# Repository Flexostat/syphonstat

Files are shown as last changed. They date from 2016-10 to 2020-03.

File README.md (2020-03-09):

usage
=====

main.py:

Note that currently this is rough code and as such you have to modify some code constats to change settings.

All configureation is in main.py toward the top.  These variables are clearly labeled.  Currently the only adjustable things are the serial port used and the OD setpoint.

To run, make sure the correct serial port is setup and execute main.py (eg in a terminal, type 'python main.py' without the single quotes).

plot.py:

Used to quickely plot data generated by main.py.  Assuming numpy/scipy are installed, just run 'python plot.py'.

<br />This work is licensed under a <a rel="license" href="http://creativecommons.org/licenses/by/4.0/">Creative Commons Attribution 4.0 International License</a>.

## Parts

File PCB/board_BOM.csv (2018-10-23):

Reference | MPN | qty | note
JP2 |  |  | 3p 0.1in header vertical
C1 |  |  | .1uF x7r or better 16v or higher
C2 |  |  | 0.01uF x7r or better 16v or higher
C3 |  |  | .1uF x7r or better 16v or higher
C4 |  |  | 4.7uF x7r or better 16v or higher
C5 |  |  | 4.7uF x7r or better 16v or higher
C6 |  |  | .1uF x7r or better 16v or higher
U2 | FT232RL
L1 | MI0805K400R-10 or similar
PV1 | 2p 0.1in header vertical
PV2 | 2p 0.1in header vertical
R1 | 180ohm 0805
R3 R5 |  | 2 | 1kohm 0805
X1 | 54602-908LF
CON1 | PJ-002BH-SMT
Q3, Q4 | CJ2302 |  | AO3418
U3 | 74HCT2G04
P1 | ST-USB-009A |  | or UJ2-BH-1-TH
U1 | R-78E05-0.5
D1 | LED, green, 0805

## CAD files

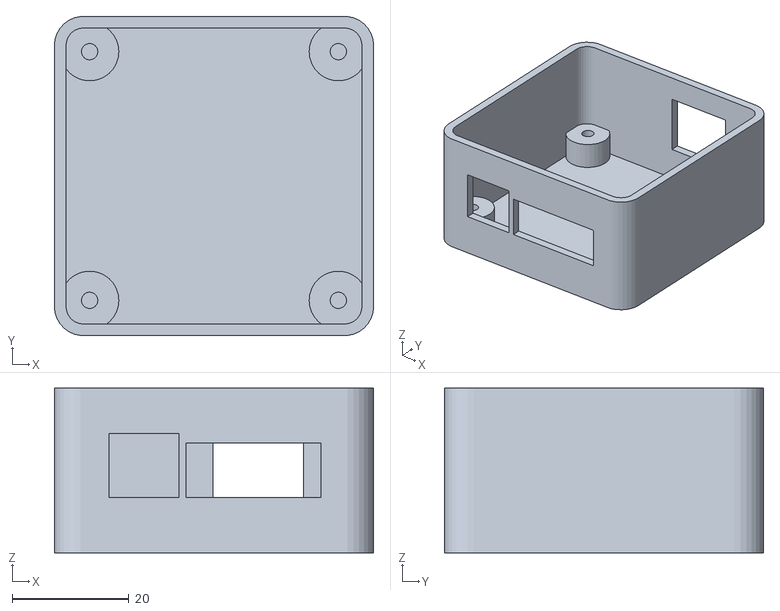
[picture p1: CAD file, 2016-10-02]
3d_printed_parts/Mainboard_base.stl
54.7 x 54.6 x 28.2

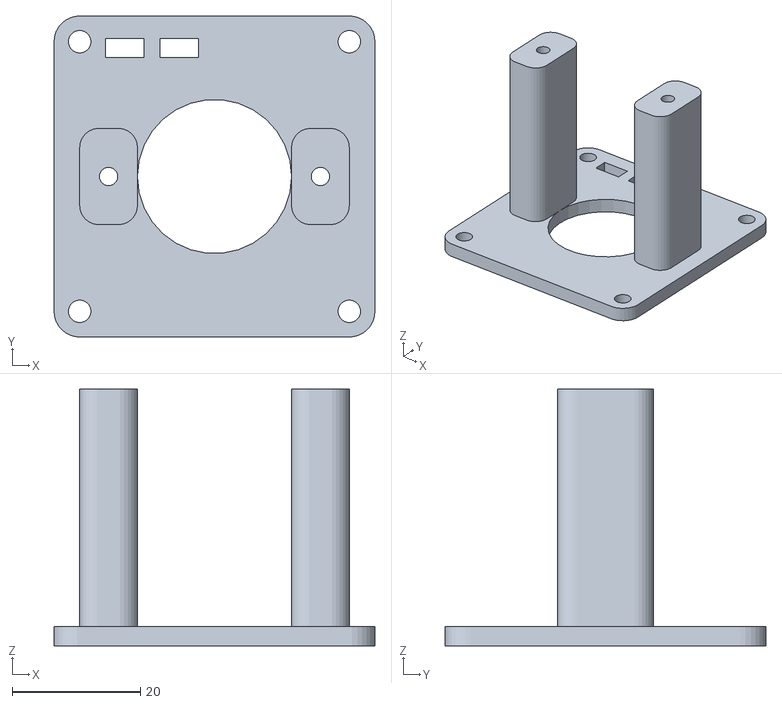
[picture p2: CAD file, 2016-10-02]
3d_printed_parts/PV_holder.stl
50.0 x 50.0 x 40.0

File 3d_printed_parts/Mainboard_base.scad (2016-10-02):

PCB_size = 50;
PCB_thick = 1.5;
extraxy=0.7;
PCB_height = 8;
oah = 30-1.75;
wall = 2;

hole_dim = (PCB_size-2*4)/2+0.3; //shouldn't need the 0.3 but it seems to. 

difference(){
    translate([-PCB_size/2-wall-extraxy/2,-PCB_size/2-wall-extraxy/2,0])
        v_rounded_cube([PCB_size+2*wall+extraxy,PCB_size+2*wall+extraxy,oah] ,5);
    
    translate([-PCB_size/2-wall-extraxy/2,-PCB_size/2-wall-extraxy/2,0])
    translate([wall,wall,wall])
        v_rounded_cube([PCB_size+extraxy,PCB_size+extraxy,2*oah],3 );
    
    //USB cutout
    translate([-PCB_size/2+7,-6-PCB_size/2,PCB_height+PCB_thick])
    cube([12,12,11]);
    //molex cutout
    translate([-23.1+PCB_size/2-6.7,-6-PCB_size/2,PCB_height+PCB_thick])
    cube([23.1,10.3,9.3]);
    //rj45 cutout
    translate([-15.5+PCB_size/2-9.7,-6+PCB_size/2,PCB_height+PCB_thick])
    cube([15.5,10,13.2]);
}
for (ii = [-hole_dim,hole_dim]){
    for (jj = [-hole_dim,hole_dim]) {
        translate([ii,jj]) mount_hole(PCB_height);
    }
}

module mount_hole(h,$fn=30) {
    difference() {
        cylinder(r=5,h=h);
        cylinder(d=2.8,h=h);
    }
}

module v_rounded_cube(xyz,r,$fn=30) {
  z = xyz[2];
  y = xyz[1];
  x = xyz[0];
  translate([r,r])
  hull() {
    cylinder(h=z,r=r);
    translate([0,y-2*r])
    cylinder(h=z,r=r);
    translate([x-2*r,0])
    cylinder(h=z,r=r);
    translate([x-2*r,y-2*r])
    cylinder(h=z,r=r);
  }
}

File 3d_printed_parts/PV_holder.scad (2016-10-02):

size =50;
tap_hole_632 = 2.85; //2.95=tap hole for 6-32.  2.85 = self taping hole for M3
difference() {
  union() {
    translate([-size/2,-size/2])
    v_rounded_cube([size,size,3],r=4);
    for (ii=[-33/2,33/2]) {
      translate([ii-9/2,-15/2,0]) v_rounded_cube([9,15,40],r=3);
    }
  }

  translate([-size/2,-size/2])
  for (ii = [4,size-4]) {
    for (jj = [4,size-4]) {
      translate([ii,jj,0]) cylinder(h=10,d=3.5 , center=true,$fn=30);
    }
  }
  cylinder(h=10,d=24 , center=true);
  for (ii=[-33/2,33/2]) {
    translate([ii,0,0]) cylinder(h=44,d=tap_hole_632 , center=false,$fn=40);
  }
  translate([-size/2+8,size/2-6.5,-1])
  cube([6,3,10]);
  translate([-size/2+8+6+0.1*25.4,size/2-6.5,-1])
  cube([6,3,10]);
}

module v_rounded_cube(xyz,r,$fn=30) {
  z = xyz[2];
  y = xyz[1];
  x = xyz[0];
  translate([r,r])
  hull() {
    cylinder(h=z,r=r);
    translate([0,y-2*r])
    cylinder(h=z,r=r);
    translate([x-2*r,0])
    cylinder(h=z,r=r);
    translate([x-2*r,y-2*r])
    cylinder(h=z,r=r);
  }
}

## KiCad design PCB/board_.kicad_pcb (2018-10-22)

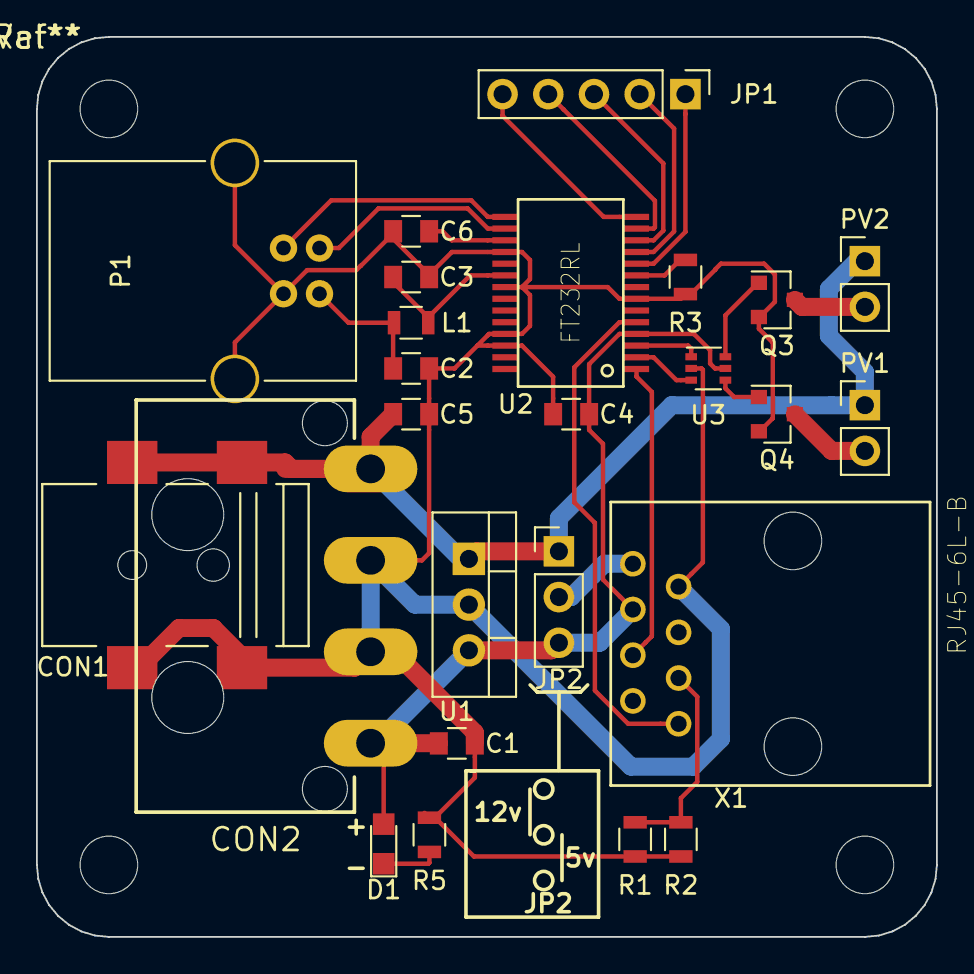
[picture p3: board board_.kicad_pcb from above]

Board: 2 copper layers, 50.0 x 50.0 mm, 26 parts (0 on the bottom side), 25 nets.

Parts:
C1, C3, C6: .1uF; C_0805
C2: 0.01uF; C_0805
C4, C5: 4.7uF; C_0805
CON1: BARREL_JACK; CUI_PJ-002BH-SMT-TR
CON2: 9090-4R; con-thomas-betts-9090-4R
D1: LED; LED_0805
JP1: Pin_Header_Straight_1x05_Pitch2.54mm
JP2: Pin_Header_Straight_1x03_Pitch2.54mm
L1: MI0805K400R-10; R_0805
P1: USB_B
PV1, PV2: Pin_Header_Straight_1x02_Pitch2.54mm
Q3, Q4: Q_NMOS_GSD; SOT-23
R1: 390; R_0805
R2: 330; R_0805
R3, R5: R_0805
Ref**: Val**; DP5050
U1: R-78x05; TO-220_Vertical
U2: FT232RL; SSOP28-LD
U3: 74HCT2G04; SOT-363_SC-70-6
X1: RJ45-6L-B; 54602-908LF

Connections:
+5V: C1.1, C4.1, CON2.1, D1.2, JP2.3, U1.3, U2.4, U3.5, X1.6
+12V: C5.1, CON1.1, CON2.4, JP2.1, PV1.1, PV2.1, U1.1
/RX1E: U2.5, X1.1
/TX1: U2.1, X1.4
GND: C1.2, C2.2, C3.2, C4.2, C5.2, C6.2, CON1.2, CON1.3, CON2.2, CON2.3, P1.4, P1.5, Q3.2, Q4.2, R1.2, R2.2, R3.2, R5.2, U1.2, U2.7, U2.18, U2.21, U2.25, U2.26, U3.2, X1.7
unnamed: JP2.2, X1.8
unnamed: C2.1, L1.1, P1.1
unnamed: C3.1, L1.2, U2.20
unnamed: C6.1, U2.17
unnamed: D1.1, R5.1
unnamed: JP1.1, U2.10
unnamed: JP1.2, U2.11
unnamed: JP1.3, U2.12
unnamed: JP1.4, U2.13
unnamed: JP1.5, U2.14
unnamed: P1.2, U2.16
unnamed: P1.3, U2.15
unnamed: PV1.2, Q4.3
unnamed: PV2.2, Q3.3
unnamed: Q3.1, U3.6
unnamed: Q4.1, U3.4
unnamed: R1.1, R2.1, X1.3
unnamed: R3.1, U2.9
unnamed: U2.2, U3.3
unnamed: U2.3, U3.1

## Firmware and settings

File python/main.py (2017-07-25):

#!/usr/bin/env python
"""Usage: main.py [options]
Options: 
 -?, --help           Prints this message and exits.
 -t, --test           Test mode: displays sensor data as (tx,rx) and exits
     --port=PORT      Sets serial port to PORT.  For windows this should be in 
                      the form COMnnn eg COM1 or COM123.  For nix/MacOS use the
                      path to the serial device eg /dev/cu.usbserial
     --setpoint=f.ff  Sets the OD set point to f.ff OD units.  eg 0.40
     --logfile=of.dat Sets the file used to wirte out log data.

Example: 
  Read sensor data to verify the device is working on COM5
main.py -t --port=COM5

  Run syphoning turbidostat on COM32 at 0.7 OD and write logs to history.dat
main.py --port=COM32 --setpoint=0.7 --logfile=history.dat
"""
from __future__ import print_function

import os
import pickle
import serial
import serial.tools.list_ports
import getopt, sys
from time import sleep, time
from math import log10

#########################################################
#BEGIN: Configuration variables
#vvvvvvvvvvvvvvvvvvvvvvvvvvvvvvvvvvvvvvvvvvvvvvvvvvvvvvvv
LOGFILE = 'log.dat'   #Name of log file
COMPORT = 'COM5'     #name of comport
SETPOINT = 0.4        #OD setpoint
#Gains: bigger kp means a faster controller but more 
# cycle-to-cycle variation in dilution volumes
# hint: keep kp/ki >15
kp = 1000
ki = 25
DILUTE_PERIOD = 60    #how often to dilute in seconds
USE_CONTROLLER_PV = True
#^^^^^^^^^^^^^^^^^^^^^^^^^^^^^^^^^^^^^^^^^^^^^^^^^^^^^^^^
#END: Configuration variables
#########################################################


class Chamber(object):
  def __init__(self,port_name):
    #init instance vars
    self._blankval = None
    self.HW_version = 10 #=v1.0

    #do HW init
    self._init_serial(port_name)

  def close_PV1(self):
    if self.HW_version<11:
      self.spt.setRTS(True)
    else:
      self.spt.setRTS(False) 

  def open_PV1(self):
    if self.HW_version<11:
      self.spt.setRTS(False)
    else:
      self.spt.setRTS(True) 

  def _init_serial(self,p):
    try:
      self.spt = serial.Serial(port = p,baudrate=19200,timeout = 0.5)
      if self.spt.getDSR():
        self.HW_version = 11 #=v1.1
      else:
        self.HW_version = 10
      self.close_PV1()

    except:
      print("Problem opening serial port " + str(p))
      print("available serial ports are: ")
      for cp in serial.tools.list_ports.comports():
        print(cp[0])
      raise ValueError('invalid port')

  def _odbytes2tuple(self,odbytes):
    #correct endianness
    #TODO: replace this with struct.unpack("<ii",data)
    txbytes = odbytes[3::-1]  #first 4bytes
    rxbytes = odbytes[7:3:-1] #next 4bytes
    tx=int(txbytes.encode('hex'),16)
    rx=int(rxbytes.encode('hex'),16)
    return (tx,rx)

  def read_raw(self):
    """
      Read the raw (tx,rx) numbers from chamber.

      This function requests tx,rx data from the chamber and decodes it into
      python int type.

      Returns (tx,rx) tuple.
      Returns None on serial timeout.
    """
    return self.dilute(0)

  def dilute(self,period):
    """
      Dilute chamber.

      period: uint8_t proportional to dilution volume.
      as of right now period = 255 should open the dilution valve for 10 seconds

      returns the current raw read value.
    """

    if period > 255:
      period = 255
    if period < 0:
      return
    period = int(round(period))
    self.spt.write(bytearray([period]))
    #read response
    b=self.spt.read(8)

    #open SPV on syphonstat board
    if USE_CONTROLLER_PV:
      self.open_PV1()
      sleep(period*5.0/1000.0) #this is not very accurate.
      self.close_PV1()

    if len(b)!=8:
      return None
    print(self._odbytes2tuple(b));
    return self._odbytes2tuple(b);

  def blank(self,blank_tuple=None):
    if blank_tuple==None:
      self._blankval = self.read_raw()
    else:
      self._blankval = blank_tuple
      
  def getblank(self):
    return self._blankval

  def read_OD(self):
    try:
      od = self.read_raw()
      signal = float(od[1])/float(od[0])
      blank = float(self._blankval[1])/float(self._blankval[0])
      return -log10(signal/blank)
    except ZeroDivisionError:
      print("WARNING! encountered division by zero.  Check" +
        "your hardware is plugged in and functioning correctly")
      return 1



if __name__ == '__main__':
  test_mode = False
  growth_test_mode = False
  #process commandline flags
  LOPTS = ["test","help","port=","setpoint=","logfile="]
  try:
    opts, args = getopt.getopt(sys.argv[1:], "tg?", LOPTS)
  except getopt.GetoptError as err:
    print(str(err))
    print("\n"+__doc__)
    sys.exit(0)
  for o,a in opts:
    if o in ("-t","--test"):
      test_mode = True
    if o in ("-?","--help"):
      print(__doc__)
      sys.exit(0)
    if o == "--port":
      COMPORT = a
    if o == "--setpoint":
      try:
        SETPOINT = float(a)
      except ValueError as err:
        print("bad argument --setpoint:")
        print(str(err))
    if o == "--logfile":
      LOGFILE = a
    if o == "-g":
      growth_test_mode = True
      print("GT mode on.")

    
  c = Chamber(COMPORT)
  if test_mode:
    print("test mode:")
    print (c.read_raw())
    c.open_PV1()
    sleep(1)
    c.close_PV1()
    dsr = c.spt.getDSR()
    cts = c.spt.getCTS()
    if dsr and not cts:
      print ("detected v1.1")
    elif not dsr and not cts:
      print ("detected v1.0")
    else:
      print ("Either not powered or wrong serial port specified")

    sys.exit(0)
  
  try:
    with open("state.dat") as f:
      temp = pickle.load(f)
    c.blank(temp['blank'])
    z = temp['z']
  except IOError:
    c.blank()
    z=0
    
  lf = open(LOGFILE,'a')
  sleep(5)
  growth_test = 0
  while True:
    OD = c.read_OD()
    #if in growth test mode dilute to setpoint -0.1 then grow to setpoint
    if growth_test_mode and time()%(8.0*60*60)<(2*60):
      growth_test = -1
    if growth_test<0:  #dilute down
      u = 255
      if OD<SETPOINT-0.1:
        growth_test=1 #go into grow mode
    elif growth_test>0:
      u=0
      if OD>SETPOINT:
        growth_test=0
    else: #normal operation
      err = OD-SETPOINT
      z = z+ki*err
      z = min(max(0.0,z),255.0) #saturate 0.0-255.0
      u = int(round(z+err*kp))
      u = min(max(0,u),255) #saturate 0-255
      try:
        with open("state.dat",'w') as f:
          pickle.dump({'z': z,'blank':c.getblank()},f)
      except KeyboardInterrupt as e:
        with open("state.dat",'w') as f:
          pickle.dump({'z': z,'blank':c.getblank()},f)
        raise e

    logline = '{' + '"time":{:d}, "OD":{:.4f}, "Z":{:.4f}, "U":{:d}'.format(int(time()),OD,z,u) +'}'
    c.dilute(u)

    print(logline)
    print(logline,file=lf)
    #force the file to get written!
    lf.flush()
    os.fsync(lf.fileno())
    sleep(DILUTE_PERIOD)

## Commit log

2014-02-25 fixed typo bug and made u saturate so it doesn't cause an integer overflow
    [main.py]
2014-02-25 fixed whitespace issue. made saving state more robust to poorly timed keyboard interrupt
    [main.py]
2015-02-13 test mode bug fix
    [main.py]
2015-02-18 fixed bug in -g
    [main.py]
2015-09-14 added optional top for holding PV
    [PV_holder.scad, PV_holder.stl]
2016-10-02 updated enclosure
    [PV_holder.scad, PV_holder.stl]
2018-10-22 added exclusings for kicad
2018-10-22 PCB files
    [board_-B.Cu.gbl, board_-B.Mask.gbs, board_-B.SilkS.gbo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]
2018-10-23 added bom
    [board_BOM.csv]
